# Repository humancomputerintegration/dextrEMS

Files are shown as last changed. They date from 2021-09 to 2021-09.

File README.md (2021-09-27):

# DextrEMS: Increasing Dexterity in Electrical Muscle Stimulation by Combining it with Brakes

This is the repository for PCB schematics and 3D printed file used in the wearable device in the "DextrEMS: Increasing Dexterity in Electrical Muscle Stimulation by Combining it with Brakes" paper (ACM UIST2021).

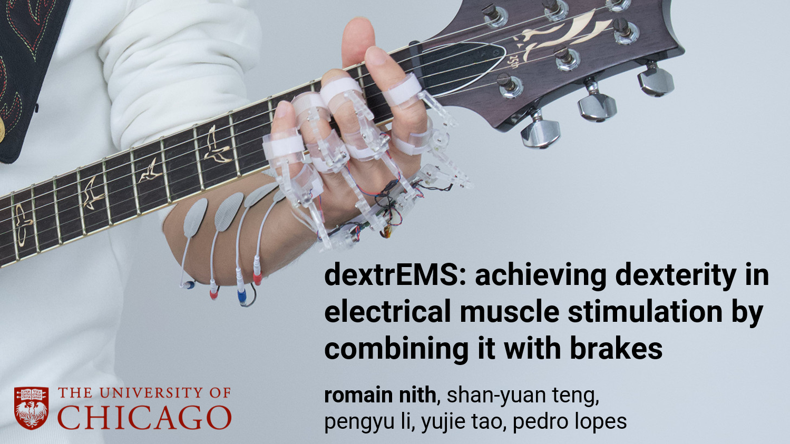
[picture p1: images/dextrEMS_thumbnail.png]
dextrems_thumbnail


## hardware

- 1x exoskeleton
- 1x electrical muscle stimulation with 8 channels (Rehastim3)

### hardware - exoskeleton

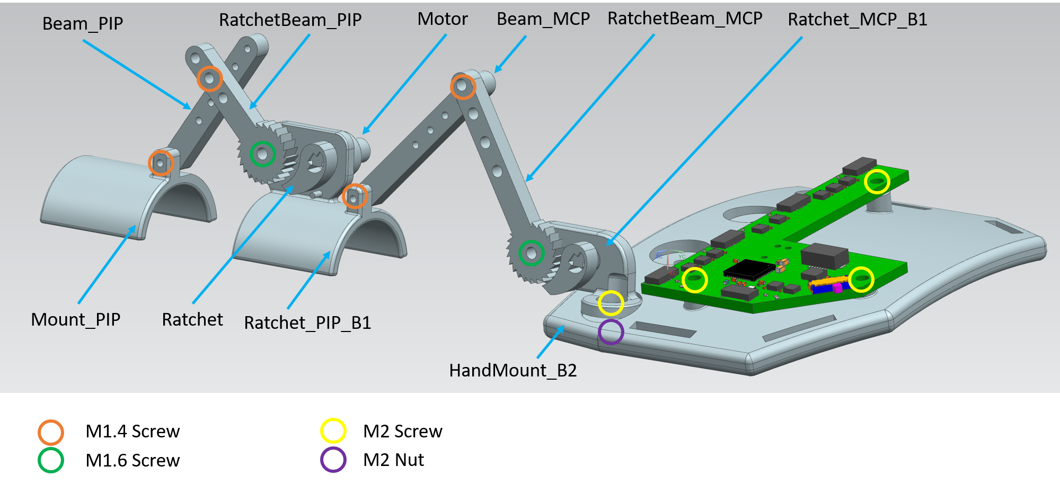
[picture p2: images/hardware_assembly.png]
hardware_assembly


#### 3D printed

- 1x HandMount_B2
- 3x Mount_PIP
- 3x Ratchet_PIP_B1
- 1x Mount_PIP_Pinky
- 1x Ratchet_PIP_Pinky
- 5x Ratchet_MCP_B1

#### laser cut (~3mm acrylic)

- 5x ratchets_n_beams_v2.ai containing:
  - 1x Beam_PIP
  - 1x RatchetBeam_PIP
  - 1x Beam_MCP
  - 1x RatchetBeam_MCP
  - 2x Ratchet

#### hardware

- 1x PCB_dextrEMS_v1
- 8x DC Motors (Vibration Motor 11.6×4.6×4.8mm, Pololu - [link](https://www.pololu.com/product/2265))
- 7x M2 Screws (4 for Ratchet_MCP and 3 for PCB)
- 16x M1.4 (for all links)
- 8x M1.6 (for all ratchet beams)
- Velcro straps (for finger and hand mounts)
- Strong glue (for bonding Velcro to 3D printed parts)
- Hot glue (optional if the ratchet and motors slide out)

## citing

When using or building upon this device in an academic publication, please consider citing as follows:

Romain Nith, Shan-Yuan Teng, Pengyu Li, Yujie Tao, Pedro Lopes. 2021. DextrEMS: Increasing Dexterity in Electrical Muscle Stimulation by Combining it with Brakes. In Proceedings of ACM Symposium on User Interface Software and Technology 2021 (UIST’2021). Association for Computing Machinery, New York, NY, USA. https://doi.org/10.1145/3472749.3474759

## contact

For any questions about this repository, please contact rnith@uchicago.edu

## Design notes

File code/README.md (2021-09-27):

# Communicating with the wireless exoskeleton

The exoskeleton communicates only using BLE. We have implemented two scripts that allow to parse the commands via WiFi using Open Sound Control (OSC) protocol and translate it to BLE for the exoskeleton. 

- `osc_server.py` allows to connect a computer with the exoskeleton via BLE. It retrieves the commands from the `osc_client.py` and sends it to the exoskeleton.
- `osc_client.py` is used to send commands to the exoskeleton.

# Technical evaluation code

The two technical evaluation's source code described in the paper are using a wired version of dextrEMS using an Arduino Mega to control the motors.

- `dextrems-independence` evaluates the independence of each joints for dextrEMS VS EMS only

- `dextrems-pose-precision` evaluates the pose precision for dextrEMS VS EMS only

# nRF Firmware

- `nrf-firmware` contains the source code for dextrEMS' firmware

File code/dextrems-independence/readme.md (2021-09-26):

# dextrems user study independency

Capture camera images for trials stimulating 4 fingers (without thumb) x 2 joints (MCP, PIP) with EMS and dextrems exoskeleton.

## software dependency

python 3 with opencv and pyserial

```
pip install opencv-python pyserial
```

## hardware

- dextrems exo wired version (Arduino MEGA)
- rehastim EMS device (8-channel)
- two webcams (should be calibrated first)
    - lowres 720p (should be number 0)
    - fhd 1080p (should be number 1)

## what this program does in steps:

1. check arduino exo
2. calibrate ems
3. read/generate user study order
4. run user study

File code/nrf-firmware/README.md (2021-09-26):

# Firmware for nRF52811

## Getting started

dextrEMS' nRF firmware is built from Nordic Semiconductor's nRF5 SDK 16.0.0 (https://www.nordicsemi.com/Products/Development-software/nRF5-SDK/Download#infotabs), based on the *ble_app_blinky* example. 

This current firmware was compiled with Segger Embedded Studio (https://www.segger.com/products/development-tools/embedded-studio/) using a 6-pin target Tag-Connect cable (https://www.tag-connect.com/product/tc2030-pkt-icespi-nl) and J-Link EDU Mini (https://www.segger.com/products/debug-probes/j-link/models/j-link-edu-mini/)

### How to install folder

Download the SDK 16.0.0 from Nordic Semiconductor's website.

In the root folder of the SDK, create a new folder called *projects*

Place the *dextrEMS* project folder in the *projects* 

Since we are using the nRF52811microcontroller with Segger Embedded Studio (SES), open the project with `projects/dextrEMS/ble_app_blinky/pca10056e/s112/ses/ble_app_blinky_pca10056e_s112.emProject`

## nRF code wiki

### How motors work

There are 3 arrays describing the motors:

- `static uint8_t motors[10]` : describes the **motor state** where 1 is locked and 0 is unlocked
- `static uint8_t motors_prev[10]` : describes the **previous motor state** which should prevent needing to update motors every time
- `static uint8_t motor_arr[20]` : describes the **motor pin** physical assignment which are defined by the following list:

```c
#define M1_1 25
#define M1_2 26
#define M2_1 27
#define M2_2 28
#define M3_1 21
#define M3_2 20
#define M4_1 19
#define M4_2 18
#define M6_1 17
#define M6_2 16
#define M5_1 15
#define M5_2 14
#define M8_1 13
#define M8_2 12
#define M7_1 11
#define M7_2 10
#define M9_1 9
#define M9_2 8
#define M10_1 7
#define M10_2 6
```

### Functions description

#### Motor functions

**The current version constantly drives the motors as the timing for locking/unlocking is not clear. Please check if the motors are running hot and turn off the motors accordingly. To test the code, please first use the LEDs to check the logic.**

```c
static void motor_init(void)
{
    uint32_t i;
    for (i = 0; i < MOTOR_NUMBER; ++i)
    {
        nrf_gpio_cfg_output(motor_arr[i]);
    }

    // init DEBUG_LED
    nrf_gpio_cfg_output(DEBUG_LED);
}
```

motor_init cycles through all the elements in motor_arr[] and set them as output. The motor pins are stored in the motor_arr[] and can be accessed easily: i.e. calling motor_arr[0] will call M1_1 and motor_arr[1] M1_2.

```c
static void unlock_all_motor()
{
    // set all motor forward to unlock
   uint32_t i;
    for (i = 0; i < MOTOR_NUMBER; ++i)
    {
        unlock_motor(i);
    }
}
```

this function cycles through all the motors and set the direction as forward which should unlock them on the exo.

NOTE: direction will depend on how the motors are wired physically. Ideally you should fix the connection at the motor connector side.

```c
void unlock_motor(uint8_t motor_idx)
{
    // set motor forward
    nrf_gpio_pin_write(motor_idx * 2, 1);
    nrf_gpio_pin_write(motor_idx * 2 + 1, 0);
}

static void lock_motor(uint8_t motor_idx)
{
    // set motor backward
    nrf_gpio_pin_write(motor_idx * 2, 0);
    nrf_gpio_pin_write(motor_idx * 2 + 1, 1);
}

static void release_motor(uint8_t motor_idx)
{
    // set motor release
    nrf_gpio_pin_write(motor_idx * 2, 0);
    nrf_gpio_pin_write(motor_idx * 2 + 1, 0);
}

static void brake_motor(uint8_t motor_idx)
{
    // set motor brake
    nrf_gpio_pin_write(motor_idx * 2, 1);
    nrf_gpio_pin_write(motor_idx * 2 + 1, 1);
}
```

The set of 4 functions are following the DRV8837 motor driver specs. Since each motor have 2 pins which are stored in motor_arr[], we need to multiply by 2 the get the correct pin assignment stored in the latter array.

```c
static void update_motors()
{
    uint8_t i;
    for (i = 0; i < MOTOR_NUMBER; ++i)
    {
        if (motors[i] == 1 && motors [i] != motors_prev[i])       // lock motor
        {
            lock_motor(i);
            motors_prev[i] = motors[i];
        }
        else if (motors[i] == 0 && motors [i] != motors_prev[i])  // unlock motor
        {
            unlock_motor(i);
            motors_prev[i] = motors[i];
        }
    }
}
```

`update_motors()` drives the motors depending on their state and previous state, which prevents the need to update every one of them at every call.

#### BLE functions

```c
static void led_write_handler(uint16_t conn_handle, ble_lbs_t * p_lbs, uint16_t msb, uint8_t lsb)
{
    NRF_LOG_INFO("BLE receive: %u and %u", msb, lsb);
    
    // Mode select
    dextrEMS_mode = ((msb>>3)&1);

    // MSB data
    motors[0] = ((msb>>1)&1);
    motors[1] = ((msb>>0)&1);

    // LSB data
    motors[2] = ((lsb>>7)&1);
    motors[3] = ((lsb>>6)&1);
    motors[4] = ((lsb>>5)&1);
    motors[5] = ((lsb>>4)&1);
    motors[6] = ((lsb>>3)&1);
    motors[7] = ((lsb>>2)&1);
    motors[8] = ((lsb>>1)&1);
    motors[9] = ((lsb>>0)&1);

    update_motors();

    // print incoming command
    NRF_LOG_INFO("Mode: %d", dextrEMS_mode);
    NRF_LOG_INFO("Binary: %u %u %u %u %u", motors[0], motors[1], motors[2], motors[3], motors[4]);
    NRF_LOG_INFO("Binary: %u %u %u %u %u", motors[5], motors[6], motors[7], motors[8], motors[9]);
}
```

This handler is called every time the nRF is receiving a BLE message. The message should come in 2 bytes hence why we have a MSByte and LSByte. This function is bit shifting the values to retrieve the motor states and storing them into the motors[] array. At the end, `update_motors()` implements the new motor states to the motor drivers.

```c
// Print incoming data. Can be called in ble_lbs.c
void debug_handler(uint16_t incoming_msg) {
   NRF_LOG_INFO("other messages: %d", incoming_msg);
}
```

This function is meant for debugging. It helps print the incoming messages received in `ble_lbs.c` to the RTT log (which can only be called in `main.c`)

In `ble_lbs.c`:

```c
static void on_write(ble_lbs_t * p_lbs, ble_evt_t const * p_ble_evt)
{
    ble_gatts_evt_write_t const * p_evt_write = &p_ble_evt->evt.gatts_evt.params.write;

    if (   (p_evt_write->handle == p_lbs->led_char_handles.value_handle)
        && (p_evt_write->len == 2) // 2 to receive 2 uint8_t packets
        && (p_lbs->led_write_handler != NULL))
    {
        p_lbs->led_write_handler(p_ble_evt->evt.gap_evt.conn_handle, p_lbs, p_evt_write->data[0], p_evt_write->data[1]); //Sending left and right bytes seperated
    }
    else {
//        debug_handler(p_evt_write->len);
    }
}
```

This function is called whenever the nRF receives a *write* value (incoming message).  It is checking if the incoming data contains 2 bytes before calling the `led_write_handler` handler. The incoming data are stored in `p_evt_write->data[]` where index `0` is the MSByte.

**Note**: this function is part of the nRF SDK, hence being shared over other projects. Before building for dextrEMS or other BLE projects based on *BLE_Blinky*, make sure you check what is inside this function.

#### Initialization/main loop

The main function starts with:

```c
// Initialize.
    log_init();
    //leds_init();
    timers_init();
    buttons_init();
    power_management_init();
    ble_stack_init();
    gap_params_init();
    gatt_init();
    services_init();
    advertising_init();
    conn_params_init();

    // motors init
    motor_init();
```

dextrEMS is not using the LEDs defined in the blinky app, hence we have to **not** initialize the *`leds_init()`*. The LED pin assignments overlaps with the motors. Furthermore, we also comment out the LED commands in the `advertising_start` and `ble_evt_handler`. To make sure you haven't missed any, search for `bsp_board_led` (`bsp_board_led_on` and `bsp_board_led_off`) which is the function used to turn on/off the LEDs

```c
// Start execution.
    NRF_LOG_INFO("dextrEMS started.");
    advertising_start();
    unlock_all_motor();
```

`advertising_start` starts the BLE advertisement.

`unlock_all_motor` unlocks all the motors.

```c
// Enter main loop.
    for (;;)
    {
        idle_state_handle();
    }
```

This should allow the nRF to manage its power as most of the code is being written around callbacks.

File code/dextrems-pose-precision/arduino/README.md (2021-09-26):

# arduino sketches

### motor_osc_serial

This Arduino sketch should be used for controlling the exo. Note that to use it with this repo's python script, a jumper needs to be place correctly on the Arduino board (refer to the sketch). This will allow to only control the ring finger's MCP brake.

The OSC component can be discarded.

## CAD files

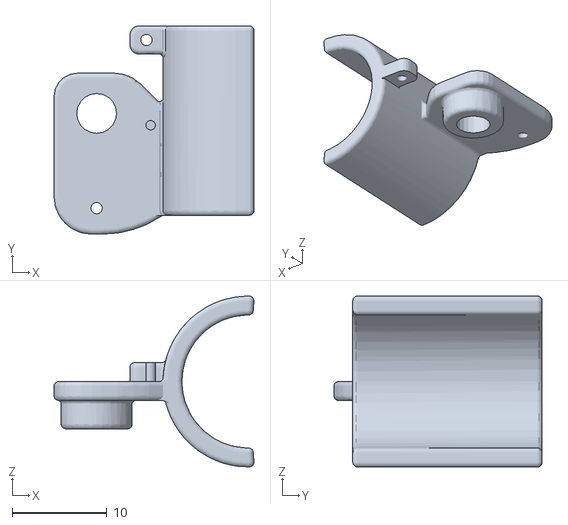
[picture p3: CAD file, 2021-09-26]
exoskeleton/3D Printed/Ractchet_PIP_Pinky_B1.stl
21.1 x 22.0 x 18.0

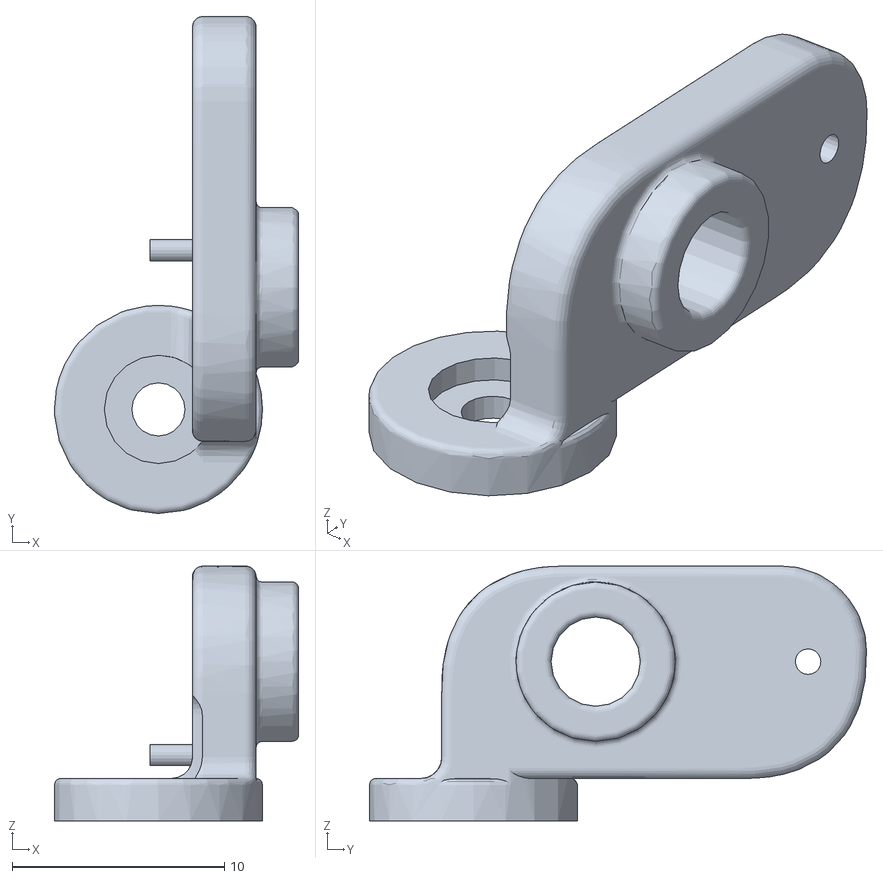
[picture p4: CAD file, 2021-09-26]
exoskeleton/3D Printed/Racthet_MCP_B1.stl
11.5 x 23.4 x 12.0

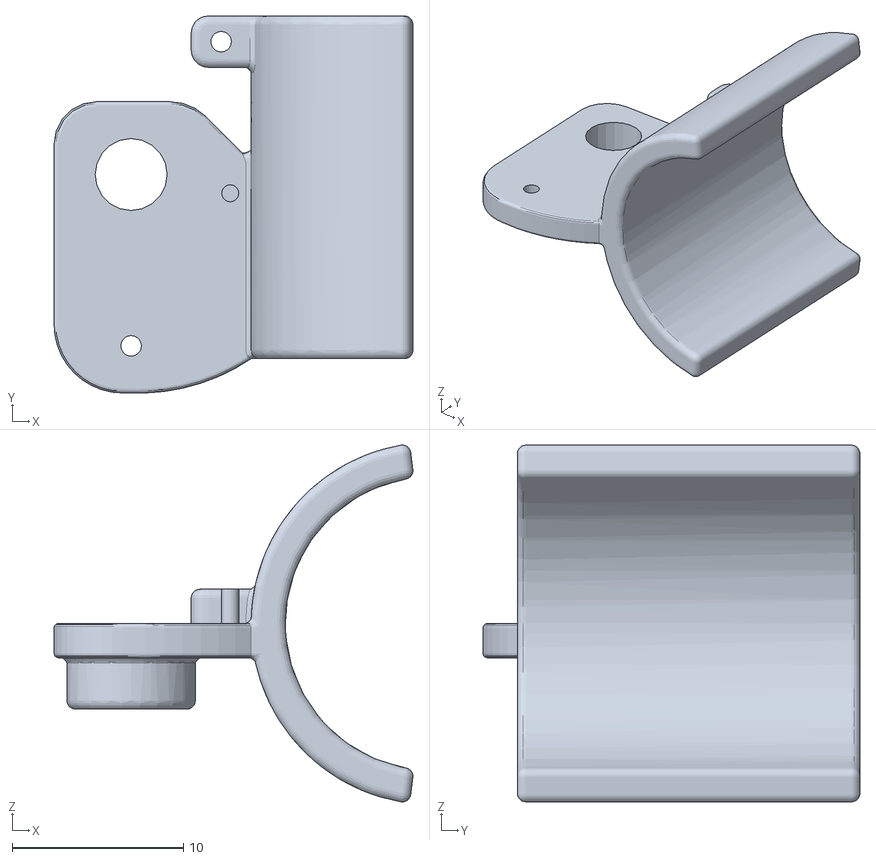
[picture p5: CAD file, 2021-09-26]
exoskeleton/3D Printed/Ractchet_PIP_B1.stl
20.9 x 22.0 x 20.8

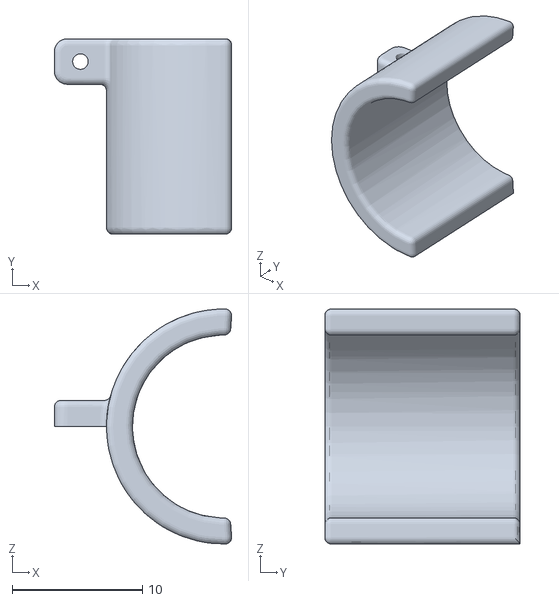
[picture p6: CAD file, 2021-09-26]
exoskeleton/3D Printed/Mount_PIP_Pinky.stl
13.6 x 15.0 x 18.0

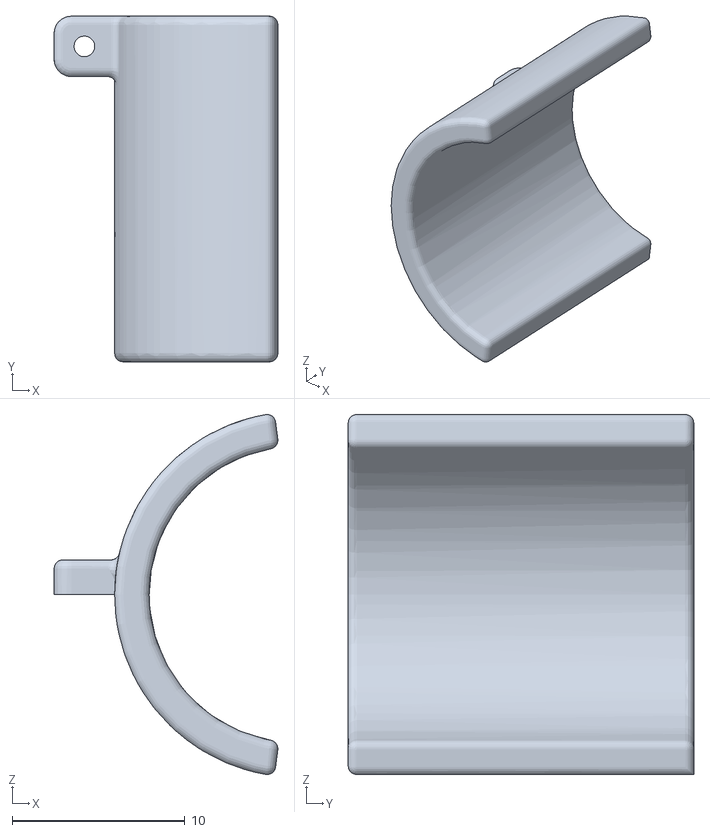
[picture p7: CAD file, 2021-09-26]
exoskeleton/3D Printed/Mount_PIP.stl
12.9 x 20.0 x 20.8

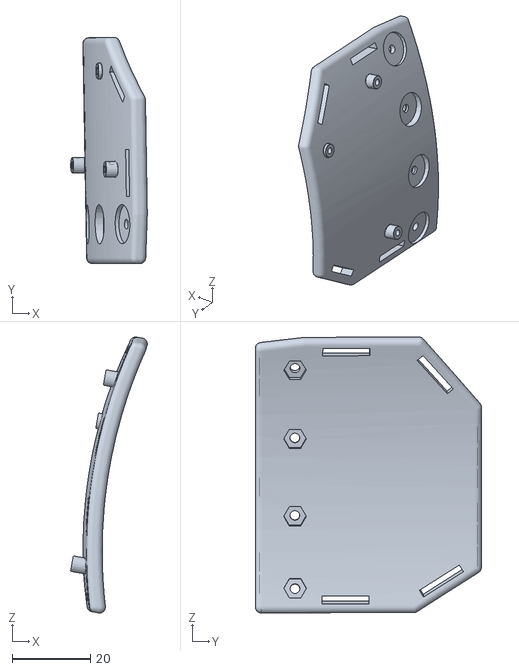
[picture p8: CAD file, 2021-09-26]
exoskeleton/3D Printed/HandMount_B2.stl
19.5 x 57.7 x 70.3

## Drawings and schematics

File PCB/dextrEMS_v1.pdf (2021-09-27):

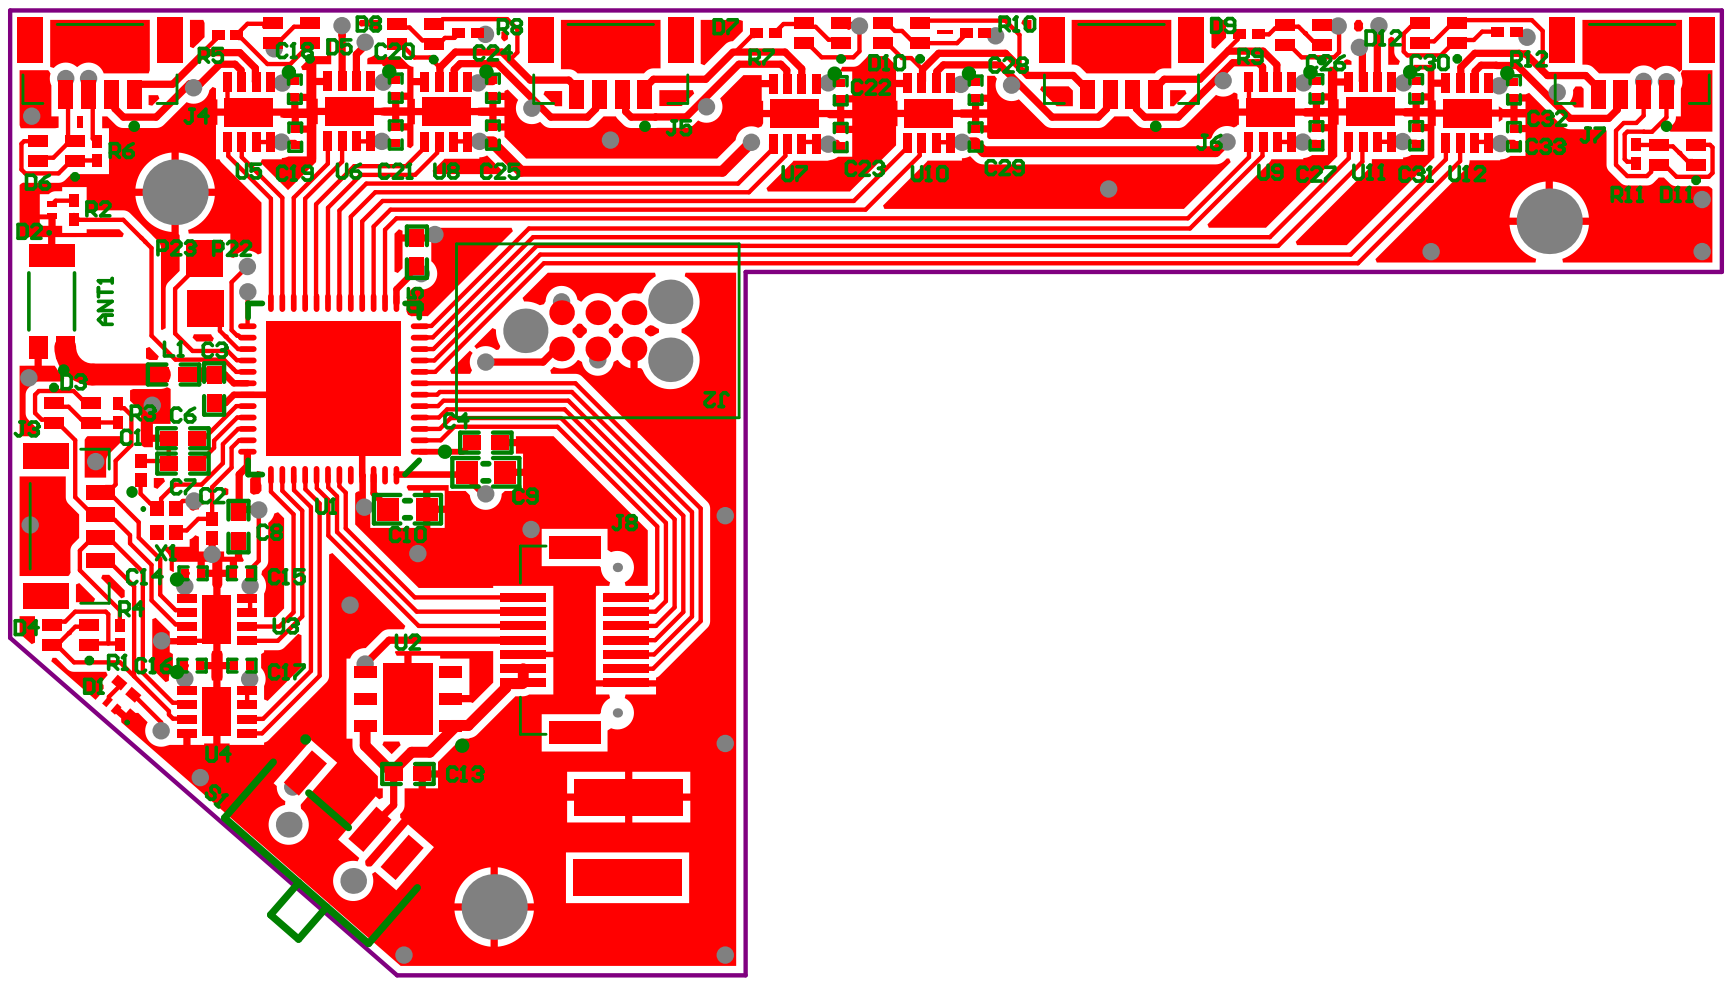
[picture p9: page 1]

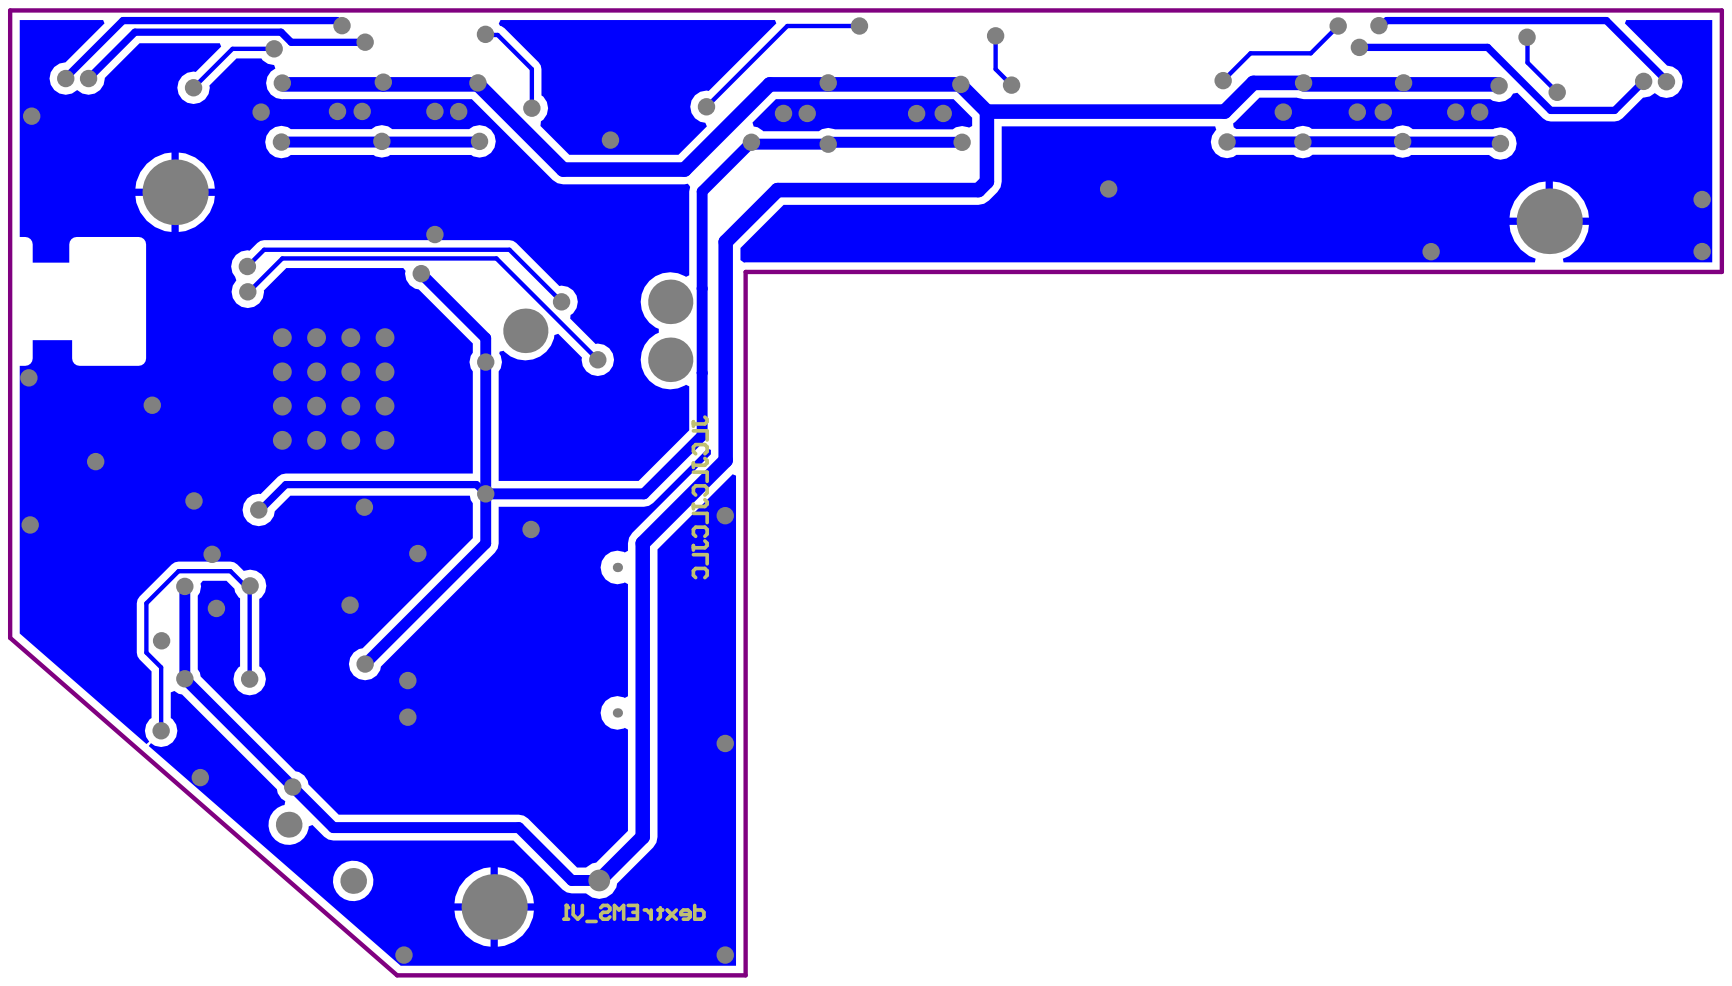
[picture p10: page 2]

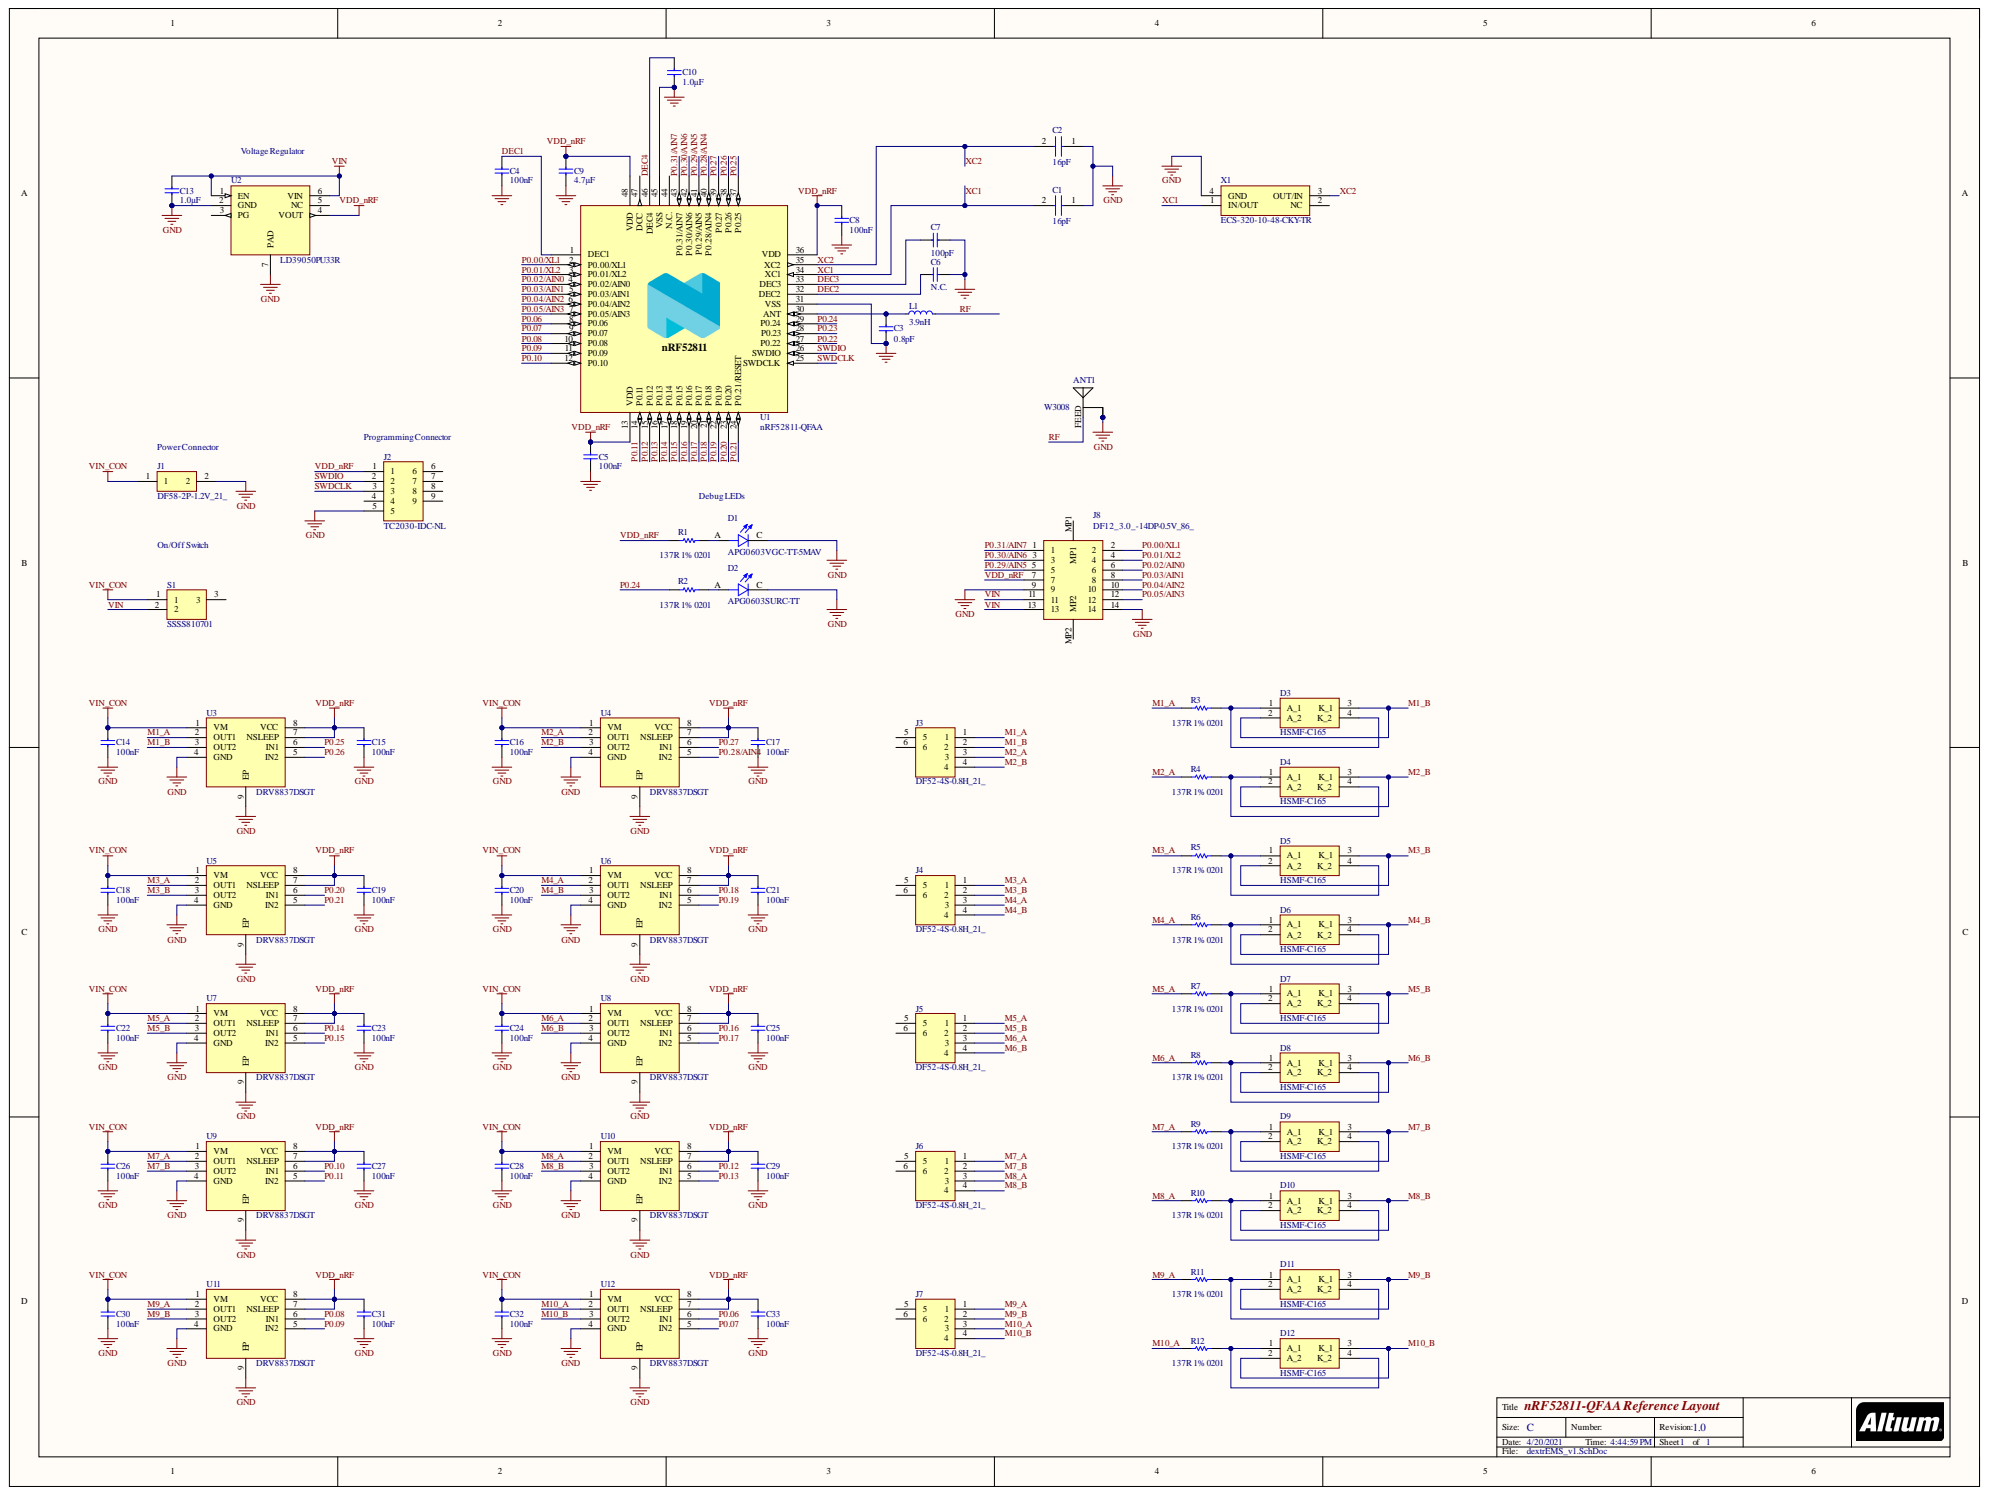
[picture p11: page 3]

DEC2

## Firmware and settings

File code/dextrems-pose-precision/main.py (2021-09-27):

''' 
DEXTREMS ACCURACY STUDY - measuring ring finger's MCP joint using Optitrack

    hardware:
    - Optitrack
    - arduino with dextrEMS exo for braking
    - rehastim for EMS
by Romain Nith and Yujie Tao
'''

import os
import serial
import time
import math
import random
import numpy as np
import csv
from datetime import datetime
import sys
import atexit

import matplotlib.pyplot as plt
import matplotlib.animation as animation

from pid_controller import PIDController
from ems_controller import EMSController
from ReadLine import ReadLine

from NatNetClient import NatNetClient

# Serial ports - change the serial port to yours
ard_angle_port  = "COM7"
ard_exo_port    = "COM3"
ems_port        = "COM4"

# Flags
opti_connected      = True   # if no optitrack, use random values
ard_exo_connected   = True   
ems_connected       = True

random_target       = False

debug               = False
debug_opti          = False
debug_filter        = False

show_plot           = False  # plot doesnt work in real time

# EMS calibrations
ems_intensity_flex = 7#8
ems_intensity_ext  = 8#9

# Targets
target_arr = [0, 8, 17, 23, 33, 45, 60, 73] # In degrees, contrained by ratchet resolution
target_index = 5 # Choose target angle
# brake_offset = 0

# PID coefficients - PID condition
PID_P        = 10 
PID_I        = 0.01 
PID_D        = 1
PID_maxOut   = 450 # clamp max pulse width
PID_minOut   = 100 # clamp min pulse width
PID_frequency= 1000  # in Hz, how fast main loop refreshes
target       = target_arr[target_index]   # in degrees
error_margin = 2    # if position is within error margin, consider target reached

# PID with exo: 2, 0.25, 1.25

# PID coefficients - EXO condition
# PID_EXO_P        = 4 
# PID_EXO_I        = 0.01 
# PID_EXO_D        = 1
# PID_EXO_maxOut   = 450 # clamp max pulse width
# PID_EXO_minOut   = 100#100 # clamp min pulse width
# PID_EXO_frequency= 30  # in Hz, how fast main loop refreshes
# error_margin_EXO = 0   # if position is within error margin, consider target reached

#                         P    I   D  minOut  maxOut  freq br_off err_marg
PID_EXO_FLEX_profiles =[[ 4, 0.01, 1,  100,    450,    50,    0,    0], # target = 0 not considered for flex
                        [ 1, 0.01, 1,  100,    450,    30,    0,    1], # target = 8
                        [ 4, 0.01, 1,  150,    450,    50,    0,    0], # target = 17
                        [ 6, 0.01, 1,  150,    450,    50,    0,    0], # target = 23
                        [ 8, 0.01, 1,  150,    450,    30,    0,    0], # target = 33
                        [ 10, 0.01, 1,  200,    450,    30,    0,    0], # target = 45
                        [ 3, 0.01, 1,  100,    450,    30,    0,    0], # target = 60
                        [ 1, 0.01, 1,  100,    450,    30,    0,    0]] # target = 73 not considered for flex

#                         P    I   D  minOut  maxOut  freq  br_off err_marg
PID_EXO_EXT_profiles = [[ 18, 0.01, 1,  200,    450,    50,    0,    5], # target = 0 
                        [ 18, 0.01, 1,  270,    450,    50,    0,    1], # target = 8
                        [ 20, 0.01, 1,  270,    450,    50,    0,    1], # target = 17
                        [ 16, 0.01, 1,  200,    450,    50,    0,    1], # target = 23
                        [ 16, 0.01, 1,  200,    450,    50,    0,    0], # target = 33
                        [ 2, 0.01, 1,  200,    450,    30,    0,    0], # target = 45
                        [ 4, 0.01, 1,  100,    450,    50,    0,    0], # target = 60 not considered for flex
                        [ 4, 0.01, 1,  100,    450,    50,    2,    0]] # target = 73 not considered for flex

# Angle variables
angle               = 0     # in degrees
angular_velocity    = 0     # in degrees/seconds
moving_avg_size     = 10    # filtering over n values
angle_array         = [0] * moving_avg_size
moving_avg_counter  = len(angle_array)
finger_heading_off  = 0
hand_heading_off    = 0

# Create figure for plotting
fig = plt.figure()
ax  = fig.add_subplot(1, 1, 1)
xs  = []
ys  = []

ROOT_DIR = os.path.dirname(os.path.abspath(__file__)) # This is your Project Root

log_path = ROOT_DIR + "/datalogging/"

log_filename_PID = datetime.now().strftime('PID-USER1-' + str(target_arr[target_index]) + '-%Y-%m-%d-%H-%M-%S.csv')
log_filename_EXO = datetime.now().strftime('EXO-USER1-' + str(target_arr[target_index]) + '-%Y-%m-%d-%H-%M-%S.csv')

def main():
    global ard_angle    
    global angle
    global prev_angle
    global prev_angle_time
    prev_angle = 0
    prev_angle_time = 0

    global ard_exo
    global brake_state
    global target_index

    study_mode = 0

    # init optitrack
    if (opti_connected):
        streamingClient = NatNetClient()

        # Configure the streaming client to call our rigid body handler on the emulator to send data out.
        streamingClient.newFrameListener = None #receiveNewFrame
        streamingClient.rigidBodyListener = receiveRigidBodyFrame

        # Start up the streaming client now that the callbacks are set up.
        # This will run perpetually, and operate on a separate thread.
        streamingClient.run()

    # init exo arduino
    if (ard_exo_connected):
        try:
            ard_exo = serial.Serial(ard_exo_port, 115200, timeout=10)
        except:
            ard_exo = 0
            print("Please check port for exo arduino")

    # init EMS device - using dummy values for init
    if (ems_connected):
        ems = EMSController(
            ems_port,
            pulse_count = 200,
            channel = 1,
            pulse_width = 6,
            intensity = 0,
        )

    if (show_plot):
        # Set up plot to call animate() function periodically
        ani = animation.FuncAnimation(fig, animate, fargs=(xs, ys), interval=1)
        plt.show(block=False)

    if (random_target):
        target_index = random.randint(0, 6)

    # -------------------------------------- STUDY STARTS HERE ------------------------------------ #

    while True: 
        if study_mode == 0:
            print ("Select a condition:")
            study_mode = int(input("1 - EMS PID, 2 - EMS EXO FLEX, 3 - EMS EXO EXT, 4 - read only angle"))

        # EMS PID condition
        elif study_mode == 1:
            # setup logging
            file = open(log_path + "/" + str(target_arr[target_index]) + "/" + log_filename_PID, 'a')
            file.write("time" + "," + "angle" + "," + "target" + "," +"PID_output" + "," + "channel" + "," + "pulse_width" + "," +
                "PID_P = " + str(PID_P) + "," + "PID_I = " + str(PID_I) + "," + "PID_D = " + str(PID_D) + "," + 
                "target = " + str(target) + "\n")

            # Time variables
            first_run = True

            angle = 0

            exo_unlock()

            # init PID controller        
            PID = PIDController(P=PID_P, I=PID_I, D=PID_D, freq=1, min=PID_minOut, max=PID_maxOut)
            PID.target = target_arr[target_index]

            print(PID.target)

            input("Curl fingers.")

            exo_lock()

            input("When at 0, press any key to zero angle.")

            # input("Lay user's hand flat to zero the angle...press any key to continue")

            # zero the angles from the 2 rigid bodies
            setOffset()

            exo_unlock()
            
            input("Ready?")

            time.sleep(random.uniform(1, 4))

            # Reset timer for first run
            time_initial = time.time()
            time_log = 0

            while True:
                # read filtered delta angle
                angle = moving_avg(read_angle())

                time_now = time.time() - time_initial # in seconds

                # update every PID_frequency Hz
                if (time_now - time_log > 1 / PID_frequency):
                    print(time_now - time_log)
                    time_log = time.time() - time_initial

                    output = PID.step(angle)

                    # need to extend more...
                    # if angle < target - error_margin:
                    # if output < 0 - error_margin:
                    if angle < target_arr[target_index] - error_margin:
                        channel = 1
                        # pulse_width_tmp = set_pulse_width(output, channel)
                        pulse_width_tmp = int(abs(output))
                     
                        if ems_connected:                        
                            ems.set_param(
                                pulse_count = 1,
                                channel     = channel,
                                pulse_width = pulse_width_tmp,
                                intensity   = ems_intensity_flex,
                            )
                            ems.send_signal()

                    # need to flex more...
                    # elif angle > target + error_margin:
                    # elif output > 0:
                    elif angle > target_arr[target_index] + error_margin:
                    
                        channel = 2
                        # pulse_width_tmp = set_pulse_width(output, channel)
                        pulse_width_tmp = int(abs(output))

                        if ems_connected:
                            ems.set_param(
                                pulse_count = 1,
                                channel     = channel,
                                pulse_width = pulse_width_tmp,
                                intensity   = ems_intensity_ext,
                            )
                            ems.send_signal()

                    # if position is within error margin, consider target reached
                    else:
                        channel = 0
                        pulse_width_tmp = 0
                        
                        print("target reached!")

                    # if angle > target_arr[target_index - brake_offset]:
                    #     exo_lock()
                        

                    # # Reset timer for first run
                    # if first_run:
                    #     time_initial = time.time()
                    #     first_run = False

                    # Log data to csv
                    file = open(log_path + "/" + str(target_arr[target_index]) + "/" + log_filename_PID, 'a')

                    file.write(str(time_log) + "," + str(angle) + "," + str(PID.target) + "," + str(output) + "," + str(channel) + "," + str(pulse_width_tmp) + "\n")
                    
                    print("angle: " + str("{0:.2f}".format(angle)) + " PID output: " + str("{0:.2f}".format(output)) +  " pulse width: " + str(pulse_width_tmp) + " channel: " + str(channel))
                    
                    if (show_plot):
                        # need pause or else plot crashes
                        plt.pause(0.001)

        # exo condition
        elif study_mode == 2:
            # Unlock joint ring mcp
            exo_unlock()

            # EMS config - flexor
            if ems_connected:
                ems.set_param(
                    pulse_count = 1,
                    channel     = 1,
                    pulse_width = 300,
                    intensity   = ems_intensity_flex,
                )

            # Setting logging
            file = open(log_path + "/" + str(target_arr[target_index]) + "/" + log_filename_EXO, 'a')
            file.write("time" + "," + "angle" + "," + "target" + "," + "output" + "," + "pulse_width" + "," + "brake_state" + "\n")

            # init PID controller
            PID_EXO = PIDController(P=PID_EXO_FLEX_profiles[target_index][0], I=PID_EXO_FLEX_profiles[target_index][1], D=PID_EXO_FLEX_profiles[target_index][2],
                                    freq=1, min=PID_EXO_FLEX_profiles[target_index][3], max=PID_EXO_FLEX_profiles[target_index][4])

            #PID_EXO = PIDController(P=PID_EXO_P, I=PID_EXO_I, D=PID_EXO_D, freq=1, min=PID_EXO_minOut, max=PID_EXO_maxOut)
            PID_EXO.target = target_arr[target_index]

            # unpacking PID profile for clarity
            PID_EXO_frequency = PID_EXO_FLEX_profiles[target_index][5]
            brake_offset = PID_EXO_FLEX_profiles[target_index][6]
            error_margin_EXO = PID_EXO_FLEX_profiles[target_index][7]
            brake_target = target_arr[target_index - brake_offset] - error_margin_EXO

            print(PID_EXO.target)
            print(brake_target)

            time.sleep(1)

            input("Curl fingers.")

            exo_lock()

            input("When at 0, press any key to zero angle.")

            # input("Lay user's hand flat to zero the angle...press any key to continue")

            # zero the angles from the 2 rigid bodies
            setOffset()

            exo_unlock()
            
            input("Ready?")

            time.sleep(random.uniform(1, 4))

            post_lock_timer = 5000
            post_lock_ems = 0

            pulse_width_tmp = 0

            # Reset timer for first run
            time_initial = time.time()
            time_lastEMS = 0

            # Continues to record after target reached for "post_lock_timer" increments
            while post_lock_timer != 0:
                # read filtered delta angle
                angle = moving_avg(read_angle())
                output = PID_EXO.step(angle)

                time_now = time.time() - time_initial # in seconds

                # angular_velocity = get_angular_velocity(angle, time_now)
                # print(angular_velocity)

                if angle < brake_target  and brake_state == 0: # or angle > target + error_margin:
                    # update every PID_frequency Hz
                    if (time_now - time_lastEMS > 1 / PID_EXO_frequency):
                        # print(time_now - time_lastEMS)
                        time_lastEMS = time_now
                        # Send EMS
                        pulse_width_tmp = int(abs(output))
                        if ems_connected:
                            ems.set_param(
                                    pulse_count = 1,
                                    channel     = 1,
                                    pulse_width = pulse_width_tmp,
                                    intensity   = ems_intensity_flex,
                                )
                            ems.send_signal()
                        # else:
                        #     print("Sending EMS...")

                else: # Target reached 
                    if post_lock_ems != 0:
                        # update every PID_frequency Hz
                        if (time_now - time_lastEMS > 1 / PID_EXO_frequency):                
                            time_lastEMS = time_now                    
                            post_lock_ems = post_lock_ems - 1
                            # Send EMS
                            pulse_width_tmp = int(abs(output))
                            if ems_connected:
                                ems.set_param(
                                    pulse_count = 1,
                                    channel     = 1,
                                    pulse_width = pulse_width_tmp,
                                    intensity   = ems_intensity_flex,
                                )
                                # ems.send_signal()
                            # else:
                            #     print("Sending EMS...")

                    if brake_state == 0: # lock joint once
                        exo_lock()

                    # Start timer 
                    post_lock_timer = post_lock_timer - 1

                # Log data to csv
                file = open(log_path + "/" + str(target_arr[target_index]) + "/" + log_filename_EXO, 'a')

                time_log = time.time() - time_initial
                file.write(str(time_log) + "," + str(angle) + "," + str(target_arr[target_index]) + "," + str(output) + "," + str(pulse_width_tmp) + "," + str(brake_state * brake_target) + "\n")

                print("angle: " + str("{0:.2f}".format(angle)) + " PID output: " + str("{0:.2f}".format(output)) +  " pulse width: " + str(pulse_width_tmp) + " brake_state: " + str(brake_state) + " timer: " + str(post_lock_timer))

                if (show_plot):
                #     # need pause or else plot crashes
                    plt.pause(0.01)
                    plt.draw()

            # Stop study
            study_mode = 0
            print("DONE!")

        # exo condition
        elif study_mode == 3:
            # Unlock joint ring mcp
            exo_unlock()

            # EMS config - flexor
            if ems_connected:
                ems.set_param(
                    pulse_count = 1,
                    channel     = 2,
                    pulse_width = 300,
                    intensity   = ems_intensity_flex,
                )

            # Setting logging
            file = open(log_path + "/" + str(target_arr[target_index]) + "/" + log_filename_EXO, 'a')
            file.write("time" + "," + "angle" + "," + "target" + "," + "output" + "," + "pulse_width" + "," + "brake_state" + "\n")

            # init PID controller
            PID_EXO = PIDController(P=PID_EXO_EXT_profiles[target_index][0], I=PID_EXO_EXT_profiles[target_index][1], D=PID_EXO_EXT_profiles[target_index][2],
                                    freq=1, min=PID_EXO_EXT_profiles[target_index][3], max=PID_EXO_EXT_profiles[target_index][4])

            #PID_EXO = PIDController(P=PID_EXO_P, I=PID_EXO_I, D=PID_EXO_D, freq=1, min=PID_EXO_minOut, max=PID_EXO_maxOut)
            PID_EXO.target = target_arr[target_index]

            # unpacking PID profile for clarity
            PID_EXO_frequency = PID_EXO_EXT_profiles[target_index][5]
            brake_offset = PID_EXO_EXT_profiles[target_index][6]
            error_margin_EXO = PID_EXO_EXT_profiles[target_index][7]
            brake_target = target_arr[target_index-brake_offset] - error_margin_EXO

            print(PID_EXO.target)

            print(brake_target)

            time.sleep(1)

            input("Curl fingers.")

            exo_lock()

            input("When at 0, press any key to zero angle.")

            # input("Lay user's hand flat to zero the angle...press any key to continue")

            # zero the angles from the 2 rigid bodies
            setOffset()

            exo_unlock()
            
            input("Ready?")

            time.sleep(random.uniform(1, 4))

            post_lock_timer = 5000
            post_lock_ems = 0

            pulse_width_tmp = 0

            # Reset timer for first run
            time_initial = time.time()
            time_lastEMS = 0

            # Continues to record after target reached for "post_lock_timer" increments
            while post_lock_timer != 0:
                # read filtered delta angle
                angle = moving_avg(read_angle())
                output = PID_EXO.step(angle)

                time_now = time.time() - time_initial # in seconds

                # angular_velocity = get_angular_velocity(angle, time_now)
                # print(angular_velocity)

                if angle > brake_target  and brake_state == 0: # or angle > target + error_margin:
                    # update every PID_frequency Hz
                    if (time_now - time_lastEMS > 1 / PID_EXO_frequency):
                        # print(time_now - time_lastEMS)
                        time_lastEMS = time_now
                        # Send EMS
                        pulse_width_tmp = int(abs(output))
                        if ems_connected:
                            ems.set_param(
                                    pulse_count = 1,
                                    channel     = 2,
                                    pulse_width = pulse_width_tmp,
                                    intensity   = ems_intensity_flex,
                                )
                            ems.send_signal()
                        # else:
                        #     print("Sending EMS...")

                else: # Target reached 
                    if post_lock_ems != 0:
                        # update every PID_frequency Hz
                        if (time_now - time_lastEMS > 1 / PID_EXO_frequency):                
                            time_lastEMS = time_now                    
                            post_lock_ems = post_lock_ems - 1
                            # Send EMS
                            pulse_width_tmp = int(abs(output))
                            if ems_connected:
                                ems.set_param(
                                    pulse_count = 1,
                                    channel     = 2,
                                    pulse_width = pulse_width_tmp,
                                    intensity   = ems_intensity_flex,
                                )
                                # ems.send_signal()
                            # else:
                            #     print("Sending EMS...")

                    if brake_state == 0: # lock joint once
                        exo_lock()

                    # Start timer 
                    post_lock_timer = post_lock_timer - 1

                # Log data to csv
                file = open(log_path + "/" + str(target_arr[target_index]) + "/" + log_filename_EXO, 'a')

                time_log = time.time() - time_initial
                file.write(str(time_log) + "," + str(angle) + "," + str(target_arr[target_index]) + "," + str(output) + "," + str(pulse_width_tmp) + "," + str(brake_state * brake_target) + "\n")

                print("angle: " + str("{0:.2f}".format(angle)) + " PID output: " + str("{0:.2f}".format(output)) +  " pulse width: " + str(pulse_width_tmp) + " brake_state: " + str(brake_state) + " timer: " + str(post_lock_timer))
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

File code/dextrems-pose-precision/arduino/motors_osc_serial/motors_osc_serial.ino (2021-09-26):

// Pinout - add thumb if available
// Thumb
const int T_PIP_EN;
const int T_PIP_CH1;
const int T_PIP_CH2;

const int T_MCP_EN;
const int T_MCP_CH1;
const int T_MCP_CH2;
// Index
const int I_PIP_EN  = 22;
const int I_PIP_CH1 = 23;
const int I_PIP_CH2 = 24;

const int I_MCP_EN  = 25;
const int I_MCP_CH1 = 26;
const int I_MCP_CH2 = 27;
// Middle
const int M_PIP_EN  = 28;
const int M_PIP_CH1 = 29;
const int M_PIP_CH2 = 30;

const int M_MCP_EN  = 31;
const int M_MCP_CH1 = 32;
const int M_MCP_CH2 = 33;
// Ring
const int R_PIP_EN  = 34;
const int R_PIP_CH1 = 35;
const int R_PIP_CH2 = 36;

const int R_MCP_EN  = 37;
const int R_MCP_CH1 = 38;
const int R_MCP_CH2 = 39;
// Pinky
const int P_PIP_EN  = 40;
const int P_PIP_CH1 = 41;
const int P_PIP_CH2 = 42;

const int P_MCP_EN  = 43;
const int P_MCP_CH1 = 44;
const int P_MCP_CH2 = 45;

// stores the motor states
uint8_t motor_state[10];
uint8_t motor_state_prev[10]; // stores previous state, preventing them to get updated everytime

// stores the motor pins
// note some channels are flipped (2 before 1) because they are wired in reverse on demo exo
uint8_t motor_arr[20] = {T_MCP_CH1, T_MCP_CH2, T_PIP_CH1, T_PIP_CH2,
                     I_MCP_CH1, I_MCP_CH2, I_PIP_CH1, I_PIP_CH2,
                     M_MCP_CH2, M_MCP_CH1, M_PIP_CH1, M_PIP_CH2,
                     R_MCP_CH2, R_MCP_CH1, R_PIP_CH2, R_PIP_CH1,
                     P_MCP_CH1, P_MCP_CH2, P_PIP_CH1, P_PIP_CH2};

// Serial communication
const byte buffSize = 40;
byte inputBuffer[buffSize];

// Set this to true if exo has thumb
bool thumb = false;

void setup() {
  if (thumb){
    pinMode(T_PIP_EN  , OUTPUT);
    pinMode(T_PIP_CH1 , OUTPUT);
    pinMode(I_PIP_CH2 , OUTPUT);
  
    pinMode(T_MCP_EN  , OUTPUT);
    pinMode(T_MCP_CH1 , OUTPUT);
    pinMode(T_MCP_CH2 , OUTPUT);
  }
  
  pinMode(I_PIP_EN  , OUTPUT);
  pinMode(I_PIP_CH1 , OUTPUT);
  pinMode(I_PIP_CH2 , OUTPUT);

  pinMode(I_MCP_EN  , OUTPUT);
  pinMode(I_MCP_CH1 , OUTPUT);
  pinMode(I_MCP_CH2 , OUTPUT);
  
  pinMode(M_PIP_EN  , OUTPUT);
  pinMode(M_PIP_CH1 , OUTPUT);
  pinMode(M_PIP_CH2 , OUTPUT);

  pinMode(M_MCP_EN  , OUTPUT);
  pinMode(M_MCP_CH1 , OUTPUT);
  pinMode(M_MCP_CH2 , OUTPUT);
  
  pinMode(R_PIP_EN  , OUTPUT);
  pinMode(R_PIP_CH1 , OUTPUT);
  pinMode(R_PIP_CH2 , OUTPUT);

  pinMode(R_MCP_EN  , OUTPUT);
  pinMode(R_MCP_CH1 , OUTPUT);
  pinMode(R_MCP_CH2 , OUTPUT);
  
  pinMode(P_PIP_EN  , OUTPUT);
  pinMode(P_PIP_CH1 , OUTPUT);
  pinMode(P_PIP_CH2 , OUTPUT);

  pinMode(P_MCP_EN  , OUTPUT);
  pinMode(P_MCP_CH1 , OUTPUT);
  pinMode(P_MCP_CH2 , OUTPUT);
  
  Serial.begin(9600);
  Serial.setTimeout(2);

  // Disable all motors at start
  if (thumb){
    digitalWrite(T_PIP_EN, LOW);
    digitalWrite(T_MCP_EN, LOW);  
  }
  digitalWrite(I_PIP_EN, LOW);
  digitalWrite(I_MCP_EN, LOW);
  digitalWrite(M_PIP_EN, LOW);
  digitalWrite(M_MCP_EN, LOW);
  digitalWrite(R_PIP_EN, LOW);
  digitalWrite(R_MCP_EN, LOW);
  digitalWrite(P_PIP_EN, LOW);
  digitalWrite(P_MCP_EN, LOW);
}

void loop() {
  if (Serial.available()) 
  {
    Serial.readBytes(inputBuffer, 2); // wait for 2 bytes in buffer
    
    // MSB data
    motor_state[0] = ((inputBuffer[0]>>1)&1);
    motor_state[1] = ((inputBuffer[0]>>0)&1);
    
    // LSB data
    motor_state[2] = ((inputBuffer[1]>>7)&1);
    motor_state[3] = ((inputBuffer[1]>>6)&1);
    motor_state[4] = ((inputBuffer[1]>>5)&1);
    motor_state[5] = ((inputBuffer[1]>>4)&1);
    motor_state[6] = ((inputBuffer[1]>>3)&1);
    motor_state[7] = ((inputBuffer[1]>>2)&1);
    motor_state[8] = ((inputBuffer[1]>>1)&1);
    motor_state[9] = ((inputBuffer[1]>>0)&1);

    updateMotors();
    printMotors();
  }
}

void printMotors(){
  Serial.print("Motors in binary: ");
  for (int i = 0; i < sizeof(motor_state); i++){
      Serial.print(motor_state[i]);
    }
  Serial.println("");
}

void updateMotors(){
  for (int i = 0; i < sizeof(motor_state); ++i)
  {
      if (motor_state[i] == 1 && motor_state [i] != motor_state_prev[i])       // lock motor
      {
          lock_motor(i);
          motor_state_prev[i] = motor_state[i];
      }
      else if (motor_state[i] == 0 && motor_state [i] != motor_state_prev[i])  // unlock motor
      {
          unlock_motor(i);
          motor_state_prev[i] = motor_state[i];
      }
  }
}

void lock_motor(int index){
  digitalWrite(motor_arr[index * 2], LOW);
  digitalWrite(motor_arr[index * 2 + 1], HIGH);
  Serial.println("Locking motor " + index);
}

void unlock_motor(int index){
  digitalWrite(motor_arr[index * 2], LOW);
  digitalWrite(motor_arr[index * 2 + 1], HIGH);
  Serial.println("Unlocking motor " + index);
}

void enableMotors(int enable){
  if (thumb){
    digitalWrite(T_PIP_EN, enable);
    digitalWrite(T_MCP_EN, enable);  
  }
  digitalWrite(I_PIP_EN, enable);
  digitalWrite(I_MCP_EN, enable);
  digitalWrite(M_PIP_EN, enable);
  digitalWrite(M_MCP_EN, enable);
  digitalWrite(R_PIP_EN, enable);
  digitalWrite(R_MCP_EN, enable);
  digitalWrite(P_PIP_EN, enable);
  digitalWrite(P_MCP_EN, enable);

  //Serial.println("enable: " + enable);
}

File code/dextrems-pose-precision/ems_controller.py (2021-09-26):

import sys

sys.path.append("rehastim-integration-lib/ems_interface/modules/")
sys.path.append(
    "rehastim-integration-lib/ems_interface/tools-and-abstractions/"
)
import singlepulse
import SerialThingy
import time
import serial

FAKE_SERIAL = False
serial_response_active = False


class EMSController:
    def __init__(self, port, pulse_count, channel, pulse_width, intensity):
        self.ems = SerialThingy.SerialThingy(FAKE_SERIAL)
        if len(port) > 1:
            self.ems.open_port(port, serial_response_active)
        else:
            self.ems.open_port(serial_response_active)

        self.channel = channel
        self.pulse_width = pulse_width
        self.intensity = intensity
        self.pulse_count = pulse_count

    def set_param(self, pulse_count, channel, pulse_width, intensity):
        self.channel = channel
        self.pulse_width = pulse_width
        self.intensity = intensity
        self.pulse_count = pulse_count

    # return null
    # self.channel = channel
    # self.pulse_width = pulse_width
    # self.intensity = intensity
    # self.pulse_count = pulse_count

    # def start(self, poort):
    #     ems = SerialThingy.SerialThingy(FAKE_SERIAL)
    #     if len(port) > 1:
    #         ems.open_port(port, serial_response_active)
    #     else:
    #         ems.open_port(serial_response_active)

    #     return ems

    def send_signal(self):
        # TODO: not sure what this open_port is, is it ok to call it every time
        # sending a signal?
        # ems = SerialThingy.SerialThingy(FAKE_SERIAL)
        # if len(port) > 1:
        #     ems.open_port(port, serial_response_active)
        # else:
        #     ems.open_port(serial_response_active)

        for i in range(self.pulse_count):
            self.ems.write(
                singlepulse.generate(
                    self.channel, self.pulse_width, self.intensity
                )
            )
            # ems.write(singlepulse.generate(channel+1, pulse_width, intensity-5))
            # channel number (1-8), pulse width (200-450) in microseconds,
            # intensity (0-100mA, limited 32mA)
            time.sleep(0.01)

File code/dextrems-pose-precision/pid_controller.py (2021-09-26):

"""HARIOMHARIBOLJAIMATAJIPITAJIKIJAIJAI"""
# Developed by Mark Tomczak (fixermark@gmail.com)
# Python class to calculate PID values

import numpy as np

def _clamp(value, limits):
    lower, upper = limits
    if value is None:
        return None
    elif upper is not None and abs(value) > upper:
        return upper * np.sign(value)
    elif lower is not None and abs(value) < lower:
        return lower * np.sign(value)
    else:
        return value

class PIDController:
    def __init__(self, P, I, D, freq, min=None, max=None):
        self.KP = P
        self.KI = I
        self.KD = D
        self.target = 0

        self.lastError = 0
        self.integrator = 0

        self.output_limits = (min, max)
        self.dt = 1/freq

    def setTarget(self, newTarget):
        self.target = newTarget
        self.integrator = 0

    def step(self, currentValue):
        error = currentValue - self.target

        output = (
            self.KP * error
            + _clamp(self.KI * self.integrator, self.output_limits)
            + self.KD * (error - self.lastError) / self.dt
        )

        output = _clamp(output, self.output_limits)

        self.lastError = error
        self.integrator += error * self.dt

        return output
